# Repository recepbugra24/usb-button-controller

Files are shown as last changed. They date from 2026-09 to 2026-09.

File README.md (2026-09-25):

# USB Button Controller

A minimal USB HID keyboard board that reads two externally wired buttons and
sends keystrokes to a host computer. No drivers required — the host enumerates
it as a standard keyboard.

Designed around the WCH CH552G, an 8-bit MCU with an integrated USB device
controller, on-chip 24 MHz oscillator and on-chip 5 V to 3.3 V regulator. This
removes the crystal, load capacitors, reset network and programming header that
a comparable AVR design would need, and cuts the controller cost from roughly
$4.70 to $0.31 per unit.

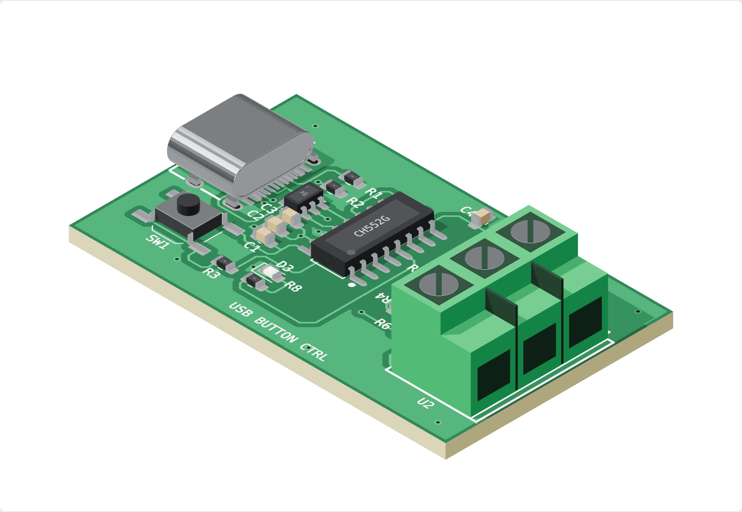
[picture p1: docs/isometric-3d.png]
Isometric 3D view of the board


An interactive version is in `docs/3d-viewer.html` (open it in a browser).

## Specifications

| | |
|---|---|
| MCU | WCH CH552G (SOP-16) |
| Interface | USB 2.0 Full Speed, USB-C connector |
| Inputs | 2 buttons, wired off-board via screw terminal |
| Power | Bus powered, ~20 mA |
| Board | 41.8 × 25.25 mm, 2 layers, 1.6 mm FR-4 |
| Assembly | Single sided (top), SMD |

## Design notes

**USB.** Both differential pairs of the USB-C receptacle are tied together so
the cable works in either orientation. CC1 and CC2 each carry a 5.1 kΩ pulldown
to advertise the board as a sink; without them the host supplies no power.
A USBLC6-2SC6 clamps ESD on D+/D- as close to the connector as layout allows.

**Button inputs.** Each channel has a 4.7 kΩ pull-up so the input never floats,
a 1 kΩ series resistor and a 100 nF capacitor forming a low-pass filter with a
0.1 ms time constant, and a second USBLC6-2SC6 protecting against discharge
carried in on the button wiring. The filter suppresses contact bounce in
hardware; firmware adds a short debounce window on top.

**Programming.** The CH552G ships with a USB bootloader in ROM. Holding SW1
while plugging in pulls D+ to V33 through a 10 kΩ resistor, which puts the chip
into bootloader mode. No external programmer is needed.

**Ground.** Copper pours on both layers, stitched with vias. The pour under the
USB pair is kept unbroken to hold the differential impedance steady.

## Repository layout

```
usb-button-controller.kicad_sch     schematic
usb-button-controller.kicad_pcb     board layout
usb-button-controller.kicad_pro     project file
docs/                   isometric render and interactive 3D viewer
gerber/                 fabrication output
  *.gtl *.gbl           copper layers
  *.gts *.gbs           solder mask
  *.gto *.gbo           silkscreen
  *.gm1                 board outline
  *.drl                 drill file
  BOM_jlcpcb.csv        bill of materials with LCSC part numbers
  usb-button-controller-all-pos.csv component placement
```

## Manufacturing

Built for JLCPCB with assembly. Upload the gerber archive, then the BOM and
placement files from `gerber/`.

Settings: 2 layers, 1.6 mm, HASL, top-side assembly. Enable **Confirm Parts
Placement** — KiCad and JLCPCB do not always agree on the zero-rotation
reference for SOT-23 and SOP packages, and the preview is where a misoriented
part gets caught.

All passives, the LED and the tactile switch are JLCPCB Basic parts. The
CH552G, USB-C receptacle, USBLC6-2SC6 and screw terminal are Extended parts and
carry a per-part setup fee.

## Firmware

Built with [ch55xduino](https://github.com/DeqingSun/ch55xduino) in the Arduino
IDE. Add this board manager URL:

```
https://raw.githubusercontent.com/DeqingSun/ch55xduino/ch55xduino/package_ch55xduino_mcs51_index.json
```

Install **CH55x Boards**, select **CH552 Board**, and pick a USB setting that
reserves RAM for HID. Pin mapping:

| Function | Port | Arduino pin |
|---|---|---|
| Button 1 | P3.3 | 33 |
| Button 2 | P3.4 | 34 |
| Status LED | P1.7 | 17 |

A blank chip enters the bootloader on its own, so the first upload needs no
button press. Later uploads are triggered automatically unless the running
firmware has locked up the USB stack, in which case hold SW1 and replug.

## Verification

- ERC clean
- DRC clean, zero unconnected items
- Schematic parity between board and schematic confirmed
- Netlist reviewed pin by pin against the CH552G datasheet

Not yet verified in hardware — no board has been built from these files.

## License

Not yet chosen. Add a LICENSE file before sharing this publicly.

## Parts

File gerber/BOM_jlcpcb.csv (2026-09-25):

Comment | Designator | Footprint | JLCPCB Part #
CH552G | U1 | SOP-16 | C111292
TYPE-C 16PIN 2MD(073) | USB1 | USB-C-SMD-16P | C2765186
USBLC6-2SC6 | D1,D2 | SOT-23-6 | C7519
KF128L-5.08-3P | U2 | KF128-3P-5.08 | C474941
100nF | C1,C2,C4 | 0603 | C14663
100nF | C5 | 0805 | C49678
10uF | C3 | 0603 | C19702
5.1k | R1,R2 | 0603 | C23186
4.7k | R4,R6 | 0603 | C23162
1k | R5,R7,R8 | 0603 | C21190
10k | R3 | 0603 | C25804
LED red | D3 | 0603 | C2286
Tact switch | SW1 | SW_SPST_TL3342 | C318884

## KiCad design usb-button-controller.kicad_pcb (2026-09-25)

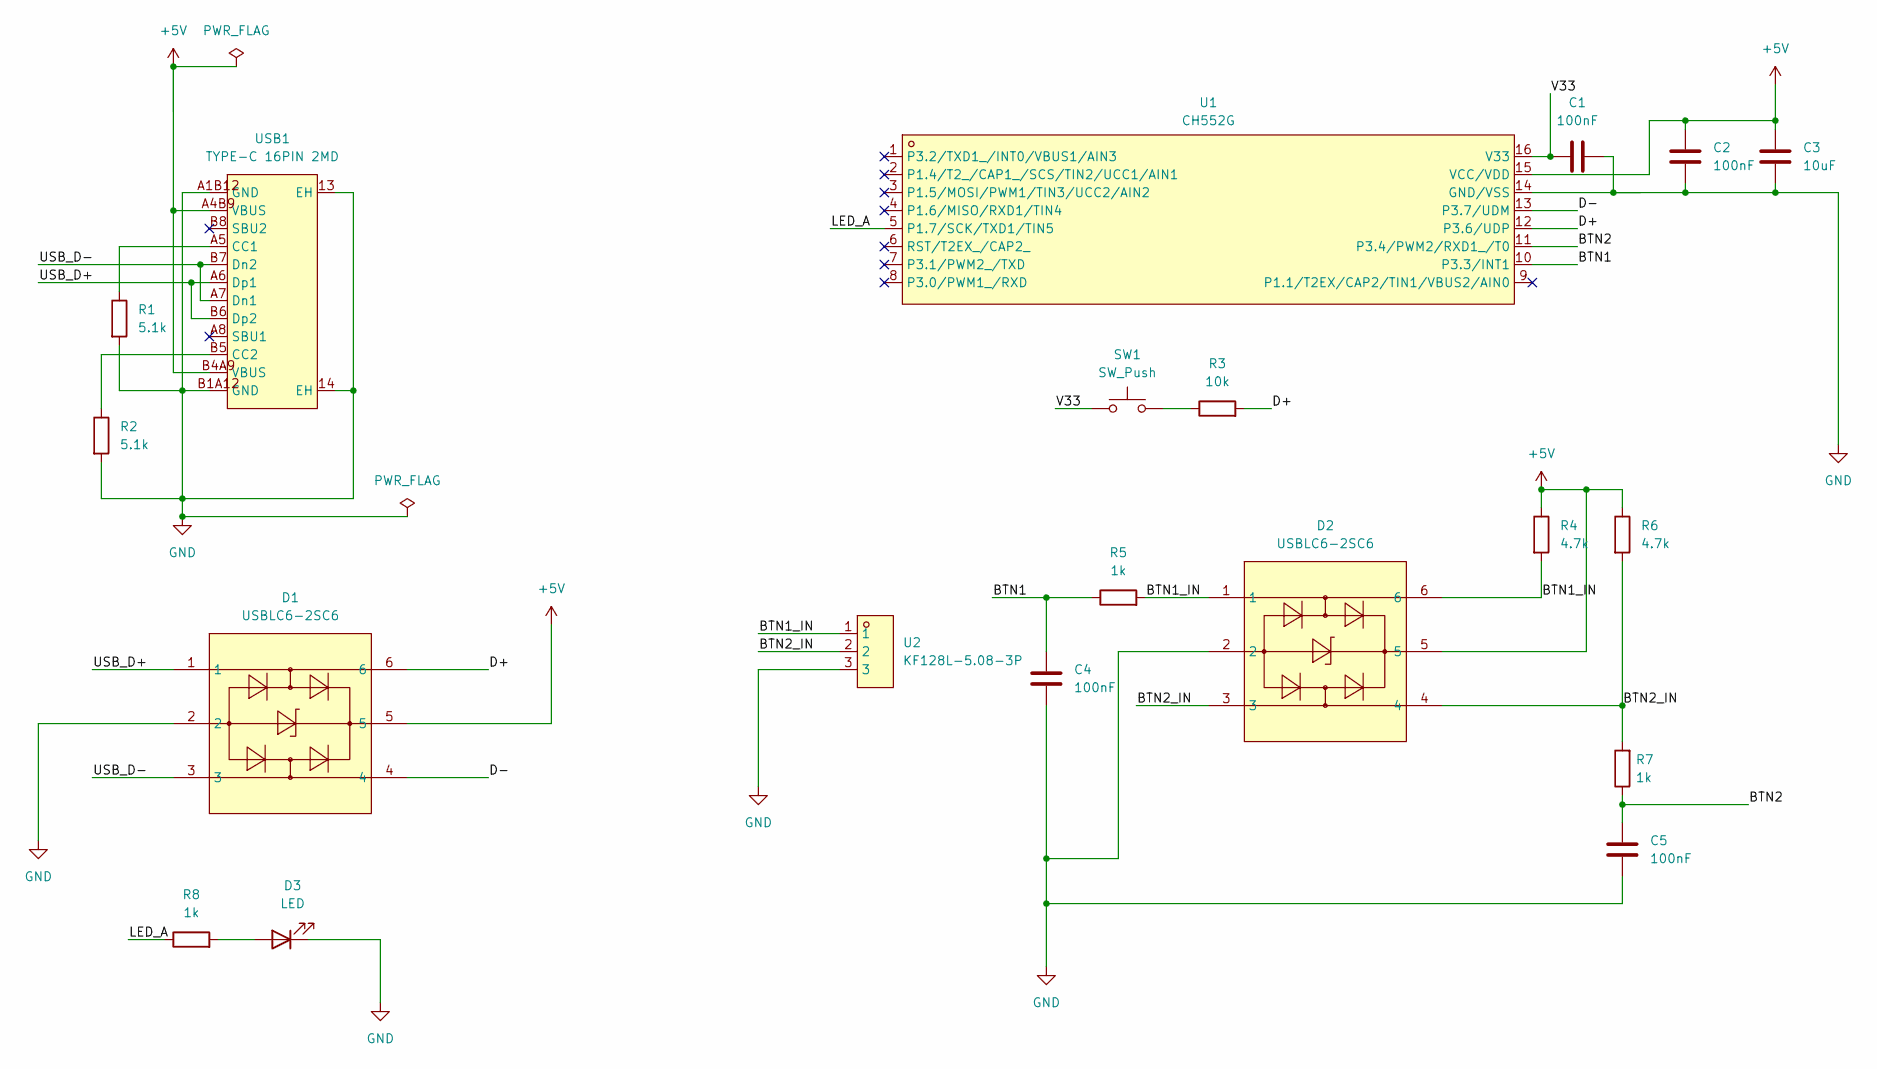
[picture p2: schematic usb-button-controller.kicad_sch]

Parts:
C1, C2, C4: 100nF; C_0603_1608Metric
C3: 10uF; C_0603_1608Metric
C5: 100nF; C_0805_2012Metric
D1, D2: USBLC6-2SC6; SOT-23-6_L2.9-W1.6-P0.95-LS2.8-BL; MPN USBLC6-2SC6; LCSC Part C7519
D3: LED; LED_0603_1608Metric
R1, R2: 5.1k; R_0603_1608Metric
R3: 10k; R_0603_1608Metric
R4, R6: 4.7k; R_0603_1608Metric
R5, R7, R8: 1k; R_0603_1608Metric
SW1: SW_Push; SW_SPST_TL3342
U1: CH552G; SOP-16_L10.0-W3.9-P1.27-LS6.0-BL; MPN CH552G; LCSC Part C111292
U2: KF128L-5.08-3P; CONN-TH_3P-P5.08_KF128L-5.08-3P; MPN KF128L-5.08-3P; LCSC Part C474941
USB1: TYPE-C 16PIN 2MD; USB-C-SMD_TYPE-C-16PIN-2MD-073; MPN TYPE-C 16PIN 2MD(073); LCSC Part C2765186

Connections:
+5V: C2.1, C3.1, D1.5, D2.5, R4.1, R6.1, U1.15 (VCC/VDD), USB1.A4B9 (VBUS), USB1.B4A9 (VBUS)
/BTN1: C4.1, R5.1, U1.10 (P3.3/INT1)
/BTN1_IN: D2.1, D2.6, R4.2, R5.2, U2.1
/BTN2: C5.1, R7.1, U1.11 (P3.4/PWM2/RXD1_/T0)
/BTN2_IN: D2.3, D2.4, R6.2, R7.2, U2.2
/D+: D1.6, R3.2, U1.12 (P3.6/UDP)
/D-: D1.4, U1.13 (P3.7/UDM)
/LED_A: R8.1, U1.5 (P1.7/SCK/TXD1/TIN5)
/USB_D+: D1.1, USB1.A6 (Dp1), USB1.B6 (Dp2)
/USB_D-: D1.3, USB1.A7 (Dn1), USB1.B7 (Dn2)
/V33: C1.1, SW1.1, U1.16 (V33)
GND: C1.2, C2.2, C3.2, C4.2, C5.2, D1.2, D2.2, D3.1 (K), R1.2, R2.2, U1.14 (GND/VSS), U2.3, USB1.13 (EH), USB1.14 (EH), USB1.A1B12 (GND), USB1.B1A12 (GND)
unnamed: D3.2 (A), R8.2
unnamed: R3.1, SW1.2
unnamed: R1.1, USB1.A5 (CC1)
unnamed: R2.1, USB1.B5 (CC2)

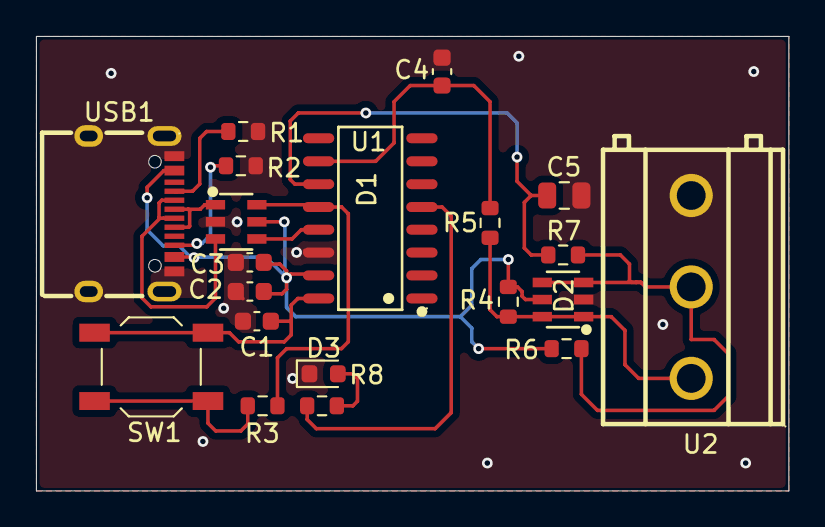
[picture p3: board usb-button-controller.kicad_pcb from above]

Board: 2 copper layers, 41.8 x 25.2 mm, 20 parts (0 on the bottom side), 16 nets.

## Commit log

2026-09-25 USB button controller: CH552G HID keyboard board
    Two off-board buttons via screw terminal, USB-C bus powered.
    Schematic and 2-layer layout complete; DRC and ERC clean,
    zero unconnected items. Includes fabrication output for
    JLCPCB assembly and an ngspice model of the debounce filter.
    [BOM_jlcpcb.csv, buton_filtre_sim.kicad_pcb, buton_filtre_sim.kicad_sch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]
2026-09-25 Rename project files to usb-button-controller
    Use English, hyphenated names throughout: KiCad project files,
    gerber output and the placement file. Update the repository
    layout section in the README to match.
    [usb-button-controller-B_Cu.gbr, usb-button-controller-B_Mask.gbr, usb-button-controller-B_Silkscreen.gbr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]
2026-09-25 Clean up the tree and rename the simulation project
    Drop the restore backup, editor history, generated netlist and
    duplicate BOM exports. Rename buton_filtre_sim to simulation and
    its files to debounce-filter.
    [debounce-filter.kicad_pcb, debounce-filter.kicad_sch, usb-button-controller.csv]
2026-09-25 Remove redundant BOM export
    [dof buton.csv]
2026-09-25 Drop the simulation project
    The ngspice model was a side experiment and was never saved with
    the circuit in place. Remove the empty project and the README
    reference to it.
    [debounce-filter.kicad_pcb, debounce-filter.kicad_sch]
2026-09-25 Regenerate fabrication output with Protel extensions
    Re-export from the renamed project so the gerbers carry the right
    project id. Board geometry is unchanged; only the embedded name,
    timestamps and filename extensions differ.
    [dof buton-all-pos.csv, usb-button-controller-B_Cu.gbl, usb-button-controller-B_Mask.gbs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]
2026-09-25 Add isometric 3D render and interactive board viewer
    Board geometry (outline, tracks, GND pours, vias, pads, silkscreen) is
    read from the .kicad_pcb file; component bodies are modelled from their
    package dimensions.
    Claude-Session: https://claude.ai/code/session_01PNy7jTuoafFGQcBf8cGsJb
